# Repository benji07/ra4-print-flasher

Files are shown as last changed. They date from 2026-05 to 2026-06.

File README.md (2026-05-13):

# Print Flasher — Pre-flasher RA-4

Outil de pre-flashing pour papier photo couleur RA-4, basé sur un Arduino Uno R4 Minima et une matrice LED WS2812 8×8. Le pre-flashing consiste à exposer brièvement le papier à une lumière de faible intensité avant l'exposition principale, pour lever les ombres et/ou introduire une dominante de correction.

## Matériel (BOM)

- 1× Arduino Uno R4 Minima
- 1× Matrice LED WS2812 8×8 (64 LEDs)
- 1× Écran OLED SSD1306 128×64 I2C (adresse `0x3C`)
- 3× Potentiomètres linéaires 10 kΩ (Y, M, durée)
- 2× Boutons poussoirs (NO)
- Câblage, fils dupont

Note : un 4ᵉ potentiomètre peut être prévu physiquement mais n'est **pas câblé** dans cette version.

## Boîtiers 3D

Modèles OpenSCAD paramétriques + STL prêts à imprimer dans [`cad/`](cad/) : une boîte LED suspendue (matrice + plexi opalin) et une boîte de commande aimantée (Arduino + pile 9V + écran + commandes). Voir [`cad/README.md`](cad/README.md) pour les instructions de génération STL, BOM impression et assemblage.

## Câblage

| Composant | Pin Arduino | Remarque |
|---|---|---|
| WS2812 — DIN | D6 | idéalement via résistance 330 Ω (voir « Recommandations électriques ») |
| WS2812 — 5V (V+ IN) | 5V | OK sur USB tant que `MASTER_BRIGHTNESS` ≤ 25 |
| WS2812 — GND (V− IN, sinon V− OUT) | GND | masse commune — voir note ci-dessous |
| OLED — SDA | SDA | broche dédiée du R4 Minima |
| OLED — SCL | SCL | broche dédiée du R4 Minima |
| OLED — VCC | 3V3 ou 5V | selon le module |
| OLED — GND | GND | |
| Bouton START | D2 → GND | `INPUT_PULLUP` côté firmware |
| Bouton OLED | D3 → GND | `INPUT_PULLUP` côté firmware |
| Pot Y (curseur) | A0 | extrémités sur 5V et GND |
| Pot M (curseur) | A1 | idem |
| Pot Durée (curseur) | A2 | idem |

```
            +5V ──┬───────────── WS2812 V+ (IN, côté DIN)
                  │
                  ├── pot Y ── A0
                  ├── pot M ── A1
                  └── pot T ── A2

            GND ──┬───────────── WS2812 V- (IN si soudable, sinon V- OUT)
                  ├── tous les pots (autre extrémité)
                  ├── bouton START ── D2
                  └── bouton OLED  ── D3

            D6 ───────────────── WS2812 DIN (IN)
            SDA ──────────────── OLED SDA
            SCL ──────────────── OLED SCL
```

### Notes sur le montage physique

- **Layout matrice : row-by-row** (pas serpentine). L'indice `i` parcourt la matrice ligne par ligne, gauche → droite, ligne 0 en haut. Pour un motif (row, col), faire `row = i / 8`, `col = i % 8`. C'est pour ça qu'avec `LIT_STRIDE = 2` on voit des **rayures verticales** et pas un damier.
- **GND matrice** : sur cette matrice, le pad V− côté **IN** n'a souvent pas de trou traversant utilisable. Si tu ne peux pas y souder, raccorde le GND côté **OUT** (V− OUT) — électriquement c'est la même masse, mais soigne le contact : une pince crocodile lâche sur ce point est un contributeur classique aux glitches data sur les WS2812.
- **R330 / cap 1000 µF** : absents dans la version actuelle du montage. Le firmware compense par des défenses logicielles (double `show()` après `clear()`, refresh périodique en IDLE). Pour un montage durable ou si tu remontes `MASTER_BRIGHTNESS`, ajoute-les (voir « Recommandations électriques »).
- **Diffuseur** : prévoir un calque / plexi dépoli posé quelques mm au-dessus de la matrice. Le `LIT_STRIDE = 2` économise du courant mais produit un éclairement non uniforme (1 LED sur 2 allumée) — le diffuseur homogénéise.

## Installation des librairies

Dans Arduino IDE → **Tools → Manage Libraries…**, installer :

- `Adafruit NeoPixel` (≥ 1.12.x — version compatible Renesas RA4M1)
- `Adafruit SSD1306`
- `Adafruit GFX Library` (s'installe automatiquement comme dépendance)

Et le board package : **Tools → Board → Boards Manager…**, installer `Arduino UNO R4 Boards`. Sélectionner ensuite `Arduino UNO R4 Minima` comme carte cible.

## Upload

1. Brancher l'Arduino en USB.
2. Sélectionner la carte `Arduino UNO R4 Minima` et le bon port série.
3. Ouvrir `print-flasher.ino`.
4. **Upload**.

## Utilisation

1. **Réglages** (matrice éteinte, OLED affichant les valeurs courantes)
   - Pot Y : densité du filtre **jaune** (atténue le canal bleu). `Y=0` ↔ pas de filtre.
   - Pot M : densité du filtre **magenta** (atténue le canal vert). `M=0` ↔ pas de filtre.
   - Pot Durée : durée du flash, de **0.1 s à 10.0 s** par pas de 0.1 s.
2. **Bouton OLED** (D3) : éteint/rallume l'écran. À utiliser quand le papier est en place pour éviter tout voile parasite.
3. **Bouton START** (D2) :
   - En IDLE : déclenche le flash. L'OLED **n'est pas touché** par ce bouton — si tu veux l'éteindre pour éviter de voiler le papier, appuie sur le bouton OLED **avant** de déclencher.
   - Pendant le flash : ré-appuyer **interrompt** immédiatement l'exposition.
4. Après le flash, brève phase « DONE » (1 s) puis retour automatique en IDLE.

### Mapping couleur (rappel)

Le firmware simule une filtration soustractive d'agrandisseur :

| Sortie LED | Formule | Effet |
|---|---|---|
| Rouge | `255` (constant) | pas de filtre cyan disponible |
| Vert  | `255 − M` | M filtre le vert |
| Bleu  | `255 − Y` | Y filtre le bleu |

- `Y=0,   M=0`   → blanc (les 3 canaux à fond, ramené à 10 % par `MASTER_BRIGHTNESS`).
- `Y=255, M=255` → rouge pur.
- `Y=0,   M=255` → magenta.
- `Y=255, M=0`   → jaune.

## Sécurité / Recommandations électriques

Le firmware fixe `MASTER_BRIGHTNESS = 25` (≈ 10 % de la luminosité max). À ce niveau :

- Pic de courant matrice ≈ **380 mA** (vs. ~3.8 A à 100 %), ce qui rentre dans les **500 mA fournis par USB** sur l'Uno R4 Minima.
- Tu peux fonctionner **sans** résistance série sur la data ni condensateur de découplage, mais c'est du proto — pas du définitif.

Si tu veux remonter `MASTER_BRIGHTNESS` au-delà de ~40, ou si la matrice fait des couleurs erratiques :

- **Résistance 330 Ω** en série entre D6 et l'entrée DIN de la première LED.
- **Condensateur 1000 µF** entre +5V et GND au plus près de la matrice.
- **Alim 5V externe ≥ 4 A**, masse commune avec l'Arduino (ne **pas** alimenter la matrice par la broche 5V de l'Arduino dans ce cas).

L'OLED émet aussi de la lumière : le bouton D3 le coupe à la demande. Le firmware **ne touche jamais** à l'état physique de l'OLED de lui-même (notamment pas pendant un flash) — c'est à toi de l'éteindre via D3 avant l'exposition si tu veux éviter tout voile parasite. Pendant le flash, le rafraîchissement du contenu est suspendu mais l'écran reste dans l'état que tu as choisi.

## Workflow conseillé

1. Avec une chute de RA-4 et ton workflow d'expo habituel, faire une **bande test pre-flash** : par exemple `Y=20, M=10, Durée=0.5 s`, puis varier la durée par paliers (0.3 / 0.5 / 0.7 / 1.0 s).
2. Une fois la **durée** calée (intensité globale du pre-flash), affiner la **balance Y/M** pour ajuster la dominante.
3. Garder une fiche des valeurs qui marchent par type de papier / type de négatif (le firmware ne mémorise pas les presets pour l'instant).

## Constantes ajustables (dans le `.ino`)

| Constante | Défaut | Effet |
|---|---|---|
| `MASTER_BRIGHTNESS` | `25` | Luminosité globale 0–255. **Ne pas dépasser 40 sur USB seul.** |
| `MIN_DURATION_MS` / `MAX_DURATION_MS` | `100` / `10000` | Plage du pot durée |
| `DURATION_STEP_MS` | `100` | Pas de quantification de la durée |
| `DEBOUNCE_MS` | `15` | Anti-rebond software des boutons |
| `OLED_REFRESH_MS` | `50` | Cadence max de rafraîchissement OLED (20 Hz, redessine seulement si valeurs changent) |
| `ANALOG_SAMPLES` | `8` | Taille de la moyenne glissante sur les pots |
| `ANALOG_SAMPLE_INTERVAL_MS` | `5` | Intervalle entre 2 échantillonnages des pots (8 × 5 ms = fenêtre de filtrage de 40 ms) |

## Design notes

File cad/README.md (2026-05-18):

# Boîtiers 3D — Print Flasher

Deux boîtes imprimables, reliées par un câble 3 fils :

- **`led_box`** (95×80×30 mm) : abrite la matrice WS2812 8×8 + plexi opalin diffuseur. Se suspend sous la tête de l'agrandisseur par un trou Ø8mm.
- **`control_box`** (150×90×35 mm) : abrite l'Arduino Uno R4 Minima + pile 9V, avec sur le panneau frontal l'OLED, 3 potentiomètres (Y/M/T) et 2 boutons (GO/OLED). Aimantée à la tête de l'agrandisseur ou posée à côté.

## Architecture de fermeture

Les deux boîtes ont la même structure :
- **Corps** = fond + paroi mince (2.4 mm) + **rebord épaissi en haut** (6.5 mm × 4 mm) qui loge les aimants Ø5×2.78mm
- **Couvercle** = simple plaque plate 4 mm, avec logements aimants en miroir
- **Alignement** par 2 ergots Ø2.5×2 mm aux coins diagonalement opposés du rebord
- Les aimants se collent à la cyano dans leurs logements ; le couvercle se "clique" sur le corps

Pour la boîte commande, 4 aimants supplémentaires sont logés dans des **bossages internes au fond** et débouchent sur la face extérieure du dos — c'est ce qui aimante la boîte à la tête métallique de l'agrandisseur.

## Génération des STL

Pré-requis : OpenSCAD installé (`brew install openscad` sur macOS).

Depuis ce dossier :

```bash
openscad -o stl/led_box_body.stl     -D 'PART="body"' led_box.scad
openscad -o stl/led_box_lid.stl      -D 'PART="lid"'  led_box.scad
openscad -o stl/control_box_body.stl -D 'PART="body"' control_box.scad
openscad -o stl/control_box_lid.stl  -D 'PART="lid"'  control_box.scad
```

Pour visualiser en preview avant export : ouvrir un `.scad` dans l'app OpenSCAD, F5 pour preview, F6 pour render.

## Paramètres ajustables

Toutes les dimensions partagées sont dans `common.scad` (tolérances, dimensions composants, épaisseurs paroi). Ajuster en haut du fichier si tes composants diffèrent — par exemple :

- `MATRIX_PCB` / `MATRIX_MTG` : si ton PCB matrice fait autre chose que 65mm avec entraxe 58mm
- `MAG_D` / `MAG_H` : pour des aimants d'autre dimensions (par défaut Ø5×2.78)
- `MAG_TOL_D` / `MAG_TOL_H` : si les aimants flottent ou ne rentrent pas dans les logements
- `RIM_W` / `RIM_H` : largeur et hauteur du rebord (par défaut 6.5×4 mm — augmenter si aimants plus gros)
- `POT_HOLE` / `BTN_HOLE` : Ø des trous panneau (par défaut 7.2 mm pour les deux types)

## BOM impression / matériel

| Élément | Quantité | Notes |
|---|---|---|
| PLA noir ou PETG noir | ~150 g | Noir = anti-fuite lumineuse |
| Aimants néodyme Ø5×2.78 mm | 24 | 8 LED fermeture (4 paires) + 12 control fermeture (6 paires) + 4 control arrière (sur fond, contre tête métallique) |
| Plexi opalin 65×65×3 mm | 1 | Diffuseur |
| Vis M2.5×6 autotaraudeuses | 4 | Fixation PCB matrice |
| Vis M3×8 autotaraudeuses | 4 | Fixation Arduino |
| Vis M2×4 autotaraudeuses | 4 | Fixation OLED |
| Câble 3 conducteurs ~22AWG | 80–120 cm | 5V / GND / Data, JST mâle aux 2 bouts |
| JST-XH 3 broches mâle (sur câble) | 2 | Un à chaque extrémité du câble |
| JST-XH 3 broches femelle | 2 | Une dans chaque boîte (soudée aux fils internes) |
| Clip pile 9V | 1 | Connecteur batterie |

## Paramètres slicer conseillés

- Couches : 0.2 mm
- Périmètres : 3 (cohérent avec WALL = 2.4mm sur buse 0.4)
- Infill : 20 % gyroid (boîte commande), 30 % (boîte LED, à cause de la suspension Ø8)
- Supports : aucun (toutes les surfaces critiques sont ≤ 45° de surplomb)
- Orientation : poser chaque pièce **fond/face en bas**, surface visible vers le haut
- Bord (brim) : 5mm si décollage observé sur la boîte commande (grande surface)

## Assemblage

1. **Coller les aimants** dans tous les logements à la cyano. Faire attention à la polarité : pour chaque paire de fermeture, le pôle de l'aimant du couvercle doit attirer celui du corps (tester avec 2 aimants à la main avant de coller). Les 4 aimants arrière de la boîte commande peuvent être collés tous dans le même sens (peu importe lequel — l'autre face est la tête métallique de l'agrandisseur).
1. **Glisser les ergots du corps dans les trous du couvercle** au moment de la fermeture — c'est ce qui empêche le couvercle de glisser latéralement.
2. **Câble inter-boîtes** :
   - Câble 3 conducteurs avec un connecteur JST-XH mâle 3 broches serti à chaque extrémité (commerce ou DIY).
3. **Boîte LED** :
   - Souder 3 fils courts sur le PCB matrice (V+, V−, DIN). V− côté **IN** si soudable, sinon **OUT** (voir [`README.md`](../README.md) racine).
   - Souder l'autre bout de ces 3 fils à une embase JST-XH 3 broches femelle.
   - Visser le PCB matrice sur ses 4 plots (M2.5).
   - Glisser le plexi opalin dans la feuillure du couvercle (par-dessous le couvercle).
   - Brancher le câble inter-boîtes (JST mâle) sur l'embase femelle interne et faire sortir le câble par l'encoche de la paroi droite (au-dessus du trou de fix).
   - Fermer le couvercle (aimants + ergots).
4. **Boîte commande** :
   - Visser l'Arduino sur ses 4 plots (M3).
   - Visser l'OLED sur les 4 plots du couvercle (M2). Souder VCC / GND / SDA / SCL aux pins correspondants.
   - Câbler 3 pots (5V / curseur sur A0,A1,A2 / GND) et 2 boutons (D2,D3 vers GND).
   - Câbler la pile 9V : (+) → VIN Arduino ; (−) → GND Arduino.
   - Glisser la pile 9V entre les 4 nervures de cale.
   - Souder 3 fils dupont 5V / GND / D6 de l'Arduino à une embase JST-XH 3 broches femelle.
   - Brancher le câble inter-boîtes (JST mâle) sur l'embase femelle et faire sortir le câble par l'encoche de la paroi gauche.
   - Fermer le couvercle (aimants + ergots).

Le câble se débranche des deux côtés (JST mâle/femelle aux 2 boîtes) — pratique pour ranger ou remplacer.

## Vérification avant impression

Ouvrir chaque STL dans le slicer et vérifier visuellement :

- **`led_box_body.stl`** : trou Ø8 dans un coin, passe-câble Ø6 sur la même paroi (X+), 4 plots PCB centrés à gauche, rebord épaissi visible en haut avec 4 logements aimants ronds + 2 ergots aux coins.
- **`led_box_lid.stl`** : plaque plate avec trou central 65×65 mm aligné sur le PCB, feuillure plexi visible sur la face inférieure, trou Ø8 dans le coin, 4 logements aimants en miroir + 2 trous d'ergots.
- **`control_box_body.stl`** : plots Arduino à gauche, cale 4 nervures à droite, encoche Ø6 sur paroi gauche, rebord épaissi en haut (6 logements aimants + 2 ergots), 4 bossages internes au fond avec logements aimants traversants (visibles depuis le dessous).
- **`control_box_lid.stl`** : plaque plate avec OLED + 5 trous Ø7.2 uniformes (Y, M, T, GO, OLED), marquages texte des labels décalés ~13 mm au-dessus des trous, logements aimants en miroir + 2 trous d'ergots.

Imprimer **un coin du rebord seul** (5×5×10 mm avec un logement aimant) pour calibrer `MAG_TOL_D` avant l'impression complète.

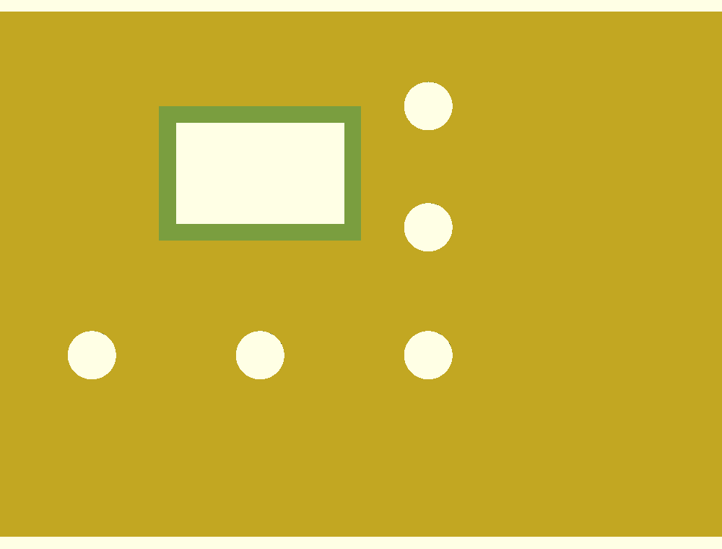
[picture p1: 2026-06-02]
cad/stl/preview_lid_control.png

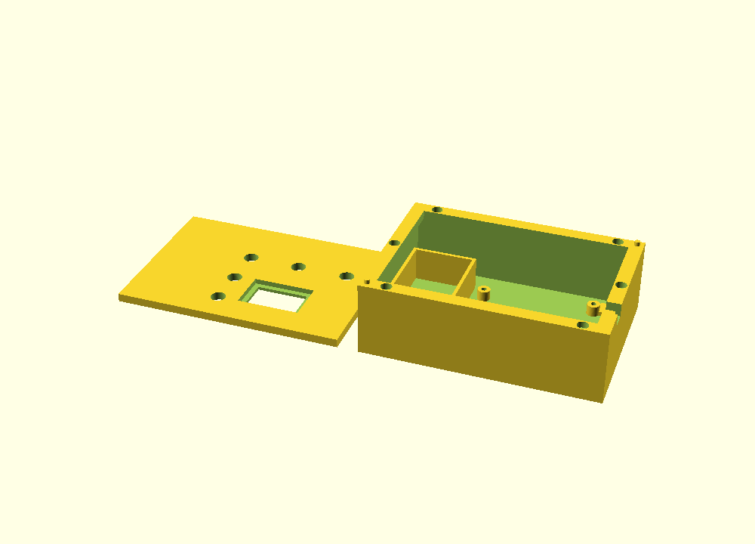
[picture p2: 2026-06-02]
cad/stl/preview_control_box.png

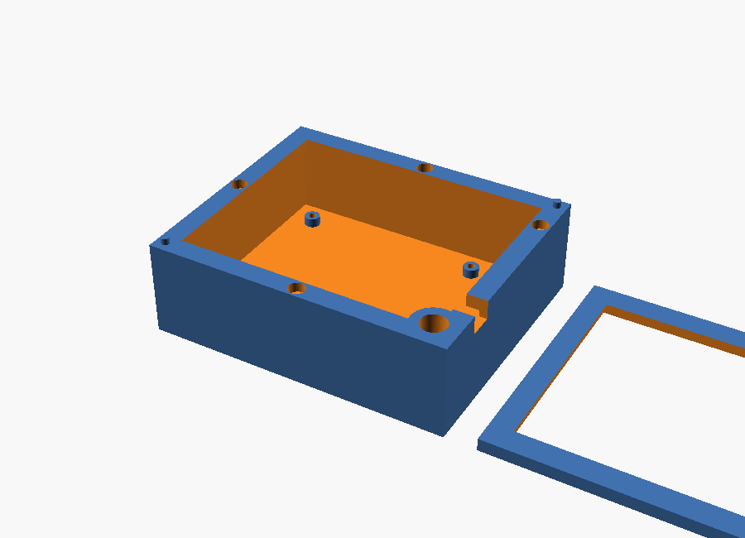
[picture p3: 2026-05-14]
cad/stl/preview_led_box.png

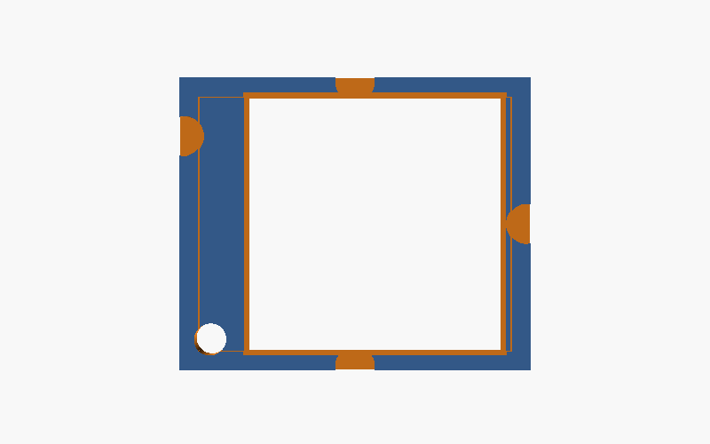
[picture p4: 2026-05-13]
cad/stl/preview_lid_led.png

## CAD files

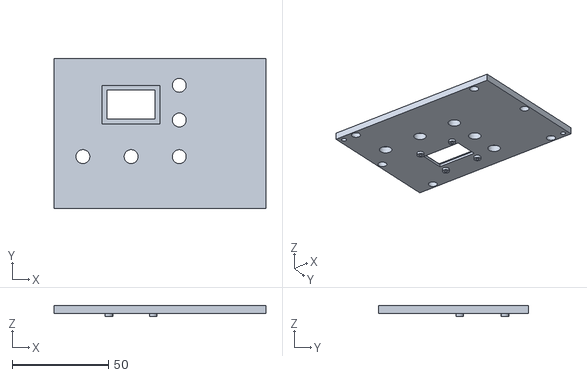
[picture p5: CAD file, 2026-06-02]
cad/stl/control_box_lid.stl
110.0 x 78.0 x 5.50

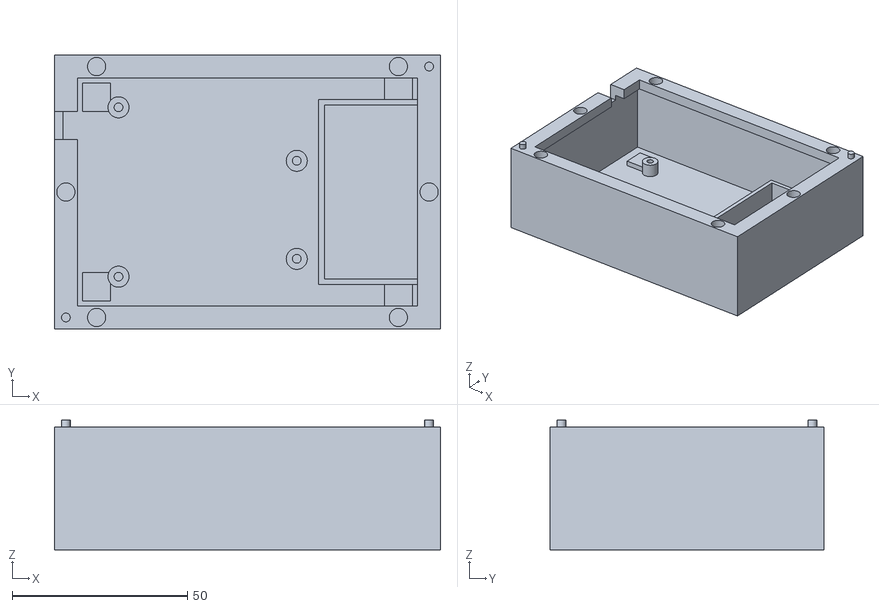
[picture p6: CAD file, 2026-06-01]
cad/stl/control_box_body.stl
110.0 x 78.0 x 37.0

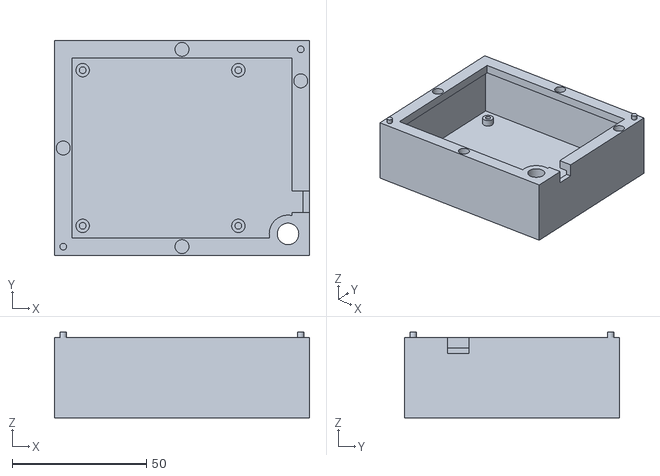
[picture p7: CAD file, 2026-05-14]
cad/stl/led_box_body.stl
95.0 x 80.0 x 32.0

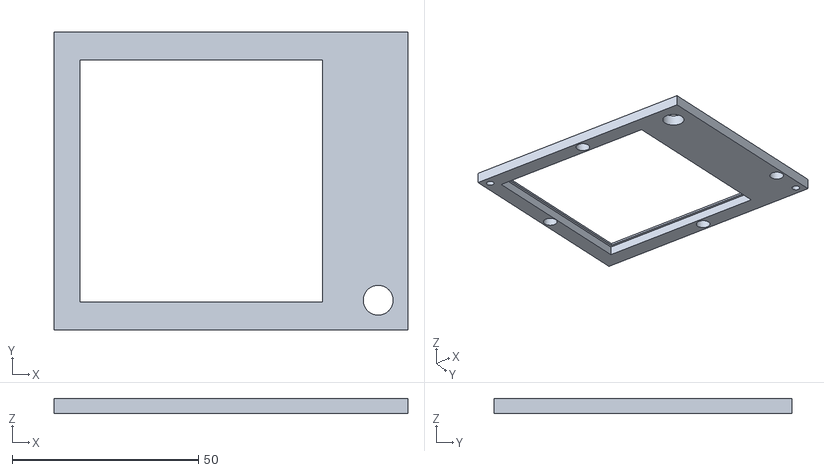
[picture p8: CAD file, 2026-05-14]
cad/stl/led_box_lid.stl
95.0 x 80.0 x 4.00

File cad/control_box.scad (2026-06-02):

// Boîte de commande — abrite l'Arduino Uno R4 Minima et la pile 9V (PP3),
// et sur le couvercle : OLED + 3 pots Y/M/T + 2 boutons GO/OLED (tous Ø7.2).
// Câble vers la boîte LED sort par la paroi gauche.
//
// Architecture : paroi mince + rebord épaissi + plaque plate.
// Aimants Ø5×2.78 : 6 en fermeture (rebord), 4 au dos (bossages internes
// au fond, débouchent sur la face extérieure pour aimanter à la tête
// d'agrandisseur). 2 ergots d'alignement.
//
// Génération STL :
//   openscad -o stl/control_box_body.stl -D 'PART="body"' control_box.scad
//   openscad -o stl/control_box_lid.stl  -D 'PART="lid"'  control_box.scad

include <common.scad>

// --- Dimensions extérieures ---
BOX_X = 110;
BOX_Y = 78;
BOX_Z = 35;

// --- Zone Arduino (PCB Uno R4 Minima, coin bas-gauche du PCB) ---
ARDUINO_X = 3;
ARDUINO_Y = (BOX_Y - ARDUINO_W) / 2;
// Trous officiels Uno (origine PCB)
ARDUINO_HOLES = [
    [15.24,  2.54],
    [15.24, 50.80],
    [66.04,  7.62],
    [66.04, 35.56]
];

// --- Zone pile 9V (à plat, calée à droite sous le rebord) ---
PP3_OUT_W  = PP3_W + PP3_TOL;    // 27.5 (petit côté, le long de X)
PP3_OUT_L  = PP3_L + PP3_TOL;    // 49.5 (long côté, le long de Y)
RIB_TH     = 1.6;
RIB_H      = 16;
PP3_X      = BOX_X - WALL - 1.6 - RIB_TH - PP3_OUT_W;   // ≈76.9
PP3_Y      = (BOX_Y - PP3_OUT_L) / 2;                   // ≈14.25, nervures symétriques

// --- Sortie câble : encoche en haut du rebord, paroi gauche X− ---
// Placée entre les aimants gauche Y=39 (milieu) et Y=74.75 (coin) pour ne pas les chevaucher.
CABLE_NOTCH_Y = 58;

// --- Couvercle : cluster regroupé (OLED + 3 pots + 2 boutons) ---
// OLED en haut, 3 pots en ligne sous l'écran (entraxe 25), 2 boutons empilés à droite.
OLED_CX = 40;  OLED_CY = 54;
POT_PITCH = 25;
POT_Y     = 27;
pot_positions = [
    [OLED_CX - POT_PITCH, POT_Y],   // [15, 27]
    [OLED_CX,             POT_Y],   // [40, 27]
    [OLED_CX + POT_PITCH, POT_Y]    // [65, 27]
];
BTN_X     = OLED_CX + POT_PITCH;    // 65 : aligné avec le pot de droite (même colonne)
btn_positions = [
    [BTN_X, 46],
    [BTN_X, 64]
];

// --- Aimants fermeture (6 sur le rebord) ---
mag_positions = [
    [12,                  MAG_PKT_OFFSET],
    [BOX_X - 12,          MAG_PKT_OFFSET],
    [12,                  BOX_Y - MAG_PKT_OFFSET],
    [BOX_X - 12,          BOX_Y - MAG_PKT_OFFSET],
    [MAG_PKT_OFFSET,      BOX_Y / 2],
    [BOX_X - MAG_PKT_OFFSET, BOX_Y / 2]
];

// --- Ergots d'alignement (2 coins diagonalement opposés) ---
peg_positions = [
    [MAG_PKT_OFFSET,         MAG_PKT_OFFSET],
    [BOX_X - MAG_PKT_OFFSET, BOX_Y - MAG_PKT_OFFSET]
];

// --- Aimants arrière (4 au dos, sur le fond, vers la tête d'agrandisseur) ---
// Les 2 du côté gauche sont sous l'Arduino, mais celui-ci est surélevé sur ses
// plots (5mm) donc aucun conflit avec le bossage (~2mm). Les 2 du côté droit sont
// décalés en Y (10 / BOX_Y-10) pour rester HORS de l'empreinte de la pile, qui
// repose directement sur le fond (sinon le bossage soulèverait la pile).
back_mag_positions = [
    [12,         12],
    [BOX_X - 12, 10],
    [12,         BOX_Y - 12],
    [BOX_X - 12, BOX_Y - 10]
];

// ─────────────────────────────────────────────────────────────────────────
module control_box_body() {
    difference() {
        union() {
            stepped_box([BOX_X, BOX_Y, BOX_Z]);
            // Plots Arduino
            for (h = ARDUINO_HOLES) {
                translate([ARDUINO_X + h.x, ARDUINO_Y + h.y, FLOOR])
                    screw_post(ARDUINO_POST_D, ARDUINO_HOLE, ARDUINO_POST_H);
            }
            // Cale pile 9V (4 nervures en U)
            translate([PP3_X - RIB_TH, PP3_Y - RIB_TH, FLOOR])
                cube([RIB_TH, PP3_OUT_L + 2*RIB_TH, RIB_H]);
            translate([PP3_X + PP3_OUT_W, PP3_Y - RIB_TH, FLOOR])
                cube([RIB_TH, PP3_OUT_L + 2*RIB_TH, RIB_H]);
            translate([PP3_X - RIB_TH, PP3_Y - RIB_TH, FLOOR])
                cube([PP3_OUT_W + 2*RIB_TH, RIB_TH, RIB_H]);
            translate([PP3_X - RIB_TH, PP3_Y + PP3_OUT_L, FLOOR])
                cube([PP3_OUT_W + 2*RIB_TH, RIB_TH, RIB_H]);
            // Bossages internes pour aimants arrière (sur la face supérieure du fond)
            for (p = back_mag_positions) floor_boss(p);
            // Ergots d'alignement
            for (p = peg_positions) rim_peg(p, BOX_Z);
        }
        // Passe-câble : encoche en haut du rebord, paroi gauche
        cable_notch("L", CABLE_NOTCH_Y, [BOX_X, BOX_Y, BOX_Z]);
        // Aimants fermeture (rebord)
        for (p = mag_positions) rim_mag_pocket(p, BOX_Z);
        // Aimants arrière (carvés depuis la face extérieure du fond, à travers le bossage)
        for (p = back_mag_positions) floor_mag_pocket(p);
    }
}

// ─────────────────────────────────────────────────────────────────────────
module control_box_lid() {
    difference() {
        union() {
            cube([BOX_X, BOX_Y, LID_TH]);
            // Plots OLED (à l'intérieur, sous le couvercle)
            translate([OLED_CX, OLED_CY, 0])
                for (sx = [-1, 1], sy = [-1, 1]) {
                    translate([sx * OLED_MTG_DX/2, sy * OLED_MTG_DY/2, -OLED_POST_H])
                        screw_post(OLED_POST_D, OLED_MTG_D, OLED_POST_H);
                }
        }
        // Fenêtre OLED (traversante)
        translate([OLED_CX - OLED_WIN_W/2, OLED_CY - OLED_WIN_H/2, -0.1])
            cube([OLED_WIN_W, OLED_WIN_H, LID_TH + 0.2]);
        // Feuillure (bezel) côté extérieur : amincit la fenêtre à ~1.5mm de membrane
        translate([OLED_CX - OLED_BEZEL_W/2, OLED_CY - OLED_BEZEL_H/2, LID_TH - OLED_BEZEL_D])
            cube([OLED_BEZEL_W, OLED_BEZEL_H, OLED_BEZEL_D + 0.1]);
        // 3 trous pots (en ligne sous l'écran) + 2 trous boutons (empilés à droite)
        for (p = pot_positions)
            translate([p.x, p.y, -0.1]) cylinder(d=POT_HOLE, h=LID_TH + 0.2);
        for (p = btn_positions)
            translate([p.x, p.y, -0.1]) cylinder(d=BTN_HOLE, h=LID_TH + 0.2);
        // Logements aimants miroirs du corps
        for (p = mag_positions) lid_mag_pocket(p);
        // Trous d'ergots
        for (p = peg_positions) lid_peg_hole(p);
    }
}

// ─────────────────────────────────────────────────────────────────────────
PART = "both";

if      (PART == "body") control_box_body();
else if (PART == "lid")  translate([0, 0, BOX_Z + 10]) control_box_lid();
else {
    control_box_body();
    translate([BOX_X + 10, 0, 0]) control_box_lid();
}

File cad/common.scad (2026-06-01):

// Variables paramétriques partagées entre led_box.scad et control_box.scad.
// Ajuster ces valeurs ici en cas de mesures différentes sur tes composants
// (PCB matrice, écrans OLED, aimants, etc.).

// --- Impression / paroi ---
WALL          = 2.4;   // épaisseur paroi standard (3 perimeters @ 0.4mm)
FLOOR         = 2.0;   // épaisseur fond
LID_TH        = 4.0;   // épaisseur couvercle (suffisante pour loger l'aimant dans le plat)
$fn           = 64;

// --- Aimants néodyme Ø5×2.78 ---
MAG_D         = 5;
MAG_H         = 2.78;
MAG_TOL_D     = 0.2;
MAG_TOL_H     = 0.2;

// --- Rebord épaissi en haut du corps (loge les aimants) ---
// Le corps a des parois minces (WALL) sur la majeure partie de sa hauteur,
// et une section plus large (RIM_W) sur les RIM_H derniers mm pour pouvoir
// percer un logement Ø(MAG_D+jeu) sans casser la paroi.
RIM_W         = 6.5;                          // largeur rebord (vue de dessus)
RIM_H         = MAG_H + MAG_TOL_H + 1.0;      // hauteur ~4mm : magnet + 1mm de matière "plafond" sous le couvercle
MAG_PKT_OFFSET = RIM_W / 2;                   // 3.25mm : centre du logement, depuis la face extérieure

// --- Ergots d'alignement couvercle/corps (2 par boîte, coins diagonalement opposés) ---
PEG_D         = 2.5;
PEG_H         = 2.0;
PEG_HOLE_D    = 2.9;                          // jeu confortable dans le couvercle
PEG_HOLE_H    = PEG_H + 0.5;

// --- Bossage interne au fond (pour les aimants arrière de la boîte commande) ---
FLOOR_BOSS_W  = MAG_D + 3;                    // 8mm carré
FLOOR_BOSS_H  = MAG_H + MAG_TOL_H + 1.0;      // mesuré depuis la face extérieure du fond

// --- Plexi opalin ---
PLEXI_TH      = 3;
PLEXI_TOL     = 0.4;

// --- Matrice WS2812 ---
MATRIX_PCB    = 65;
MATRIX_HOLE   = 65;
MATRIX_MTG    = 58;
MATRIX_MTG_D  = 2.5;
MATRIX_POST_D = 5;
MATRIX_POST_H = 3;

// --- Composants panneau ---
POT_HOLE      = 7.2;    // Ø trou pot R09
BTN_HOLE      = 7.2;    // Ø trou bouton 6×6mm avec capuchon — corrigé d'après le modèle utilisateur
OLED_WIN_W    = 25;
OLED_WIN_H    = 15;
OLED_OUTER    = 28;
OLED_MTG_DX   = 23;
OLED_MTG_DY   = 23.5;
OLED_MTG_D    = 1.8;
OLED_POST_D   = 4;
OLED_POST_H   = 1.5;   // plots courts : le verre du LCD (~1mm saillant) arrive ~0.5mm
                       // sous la face interne au lieu de ~3mm avec les anciens 4mm.
// Feuillure (bezel) côté EXTÉRIEUR : amincit le tunnel de la fenêtre de 4mm à ~1.5mm
// de membrane, pour que l'écran lise proche de la surface. Rebord large (~2.5mm) robuste.
// (Un lamage côté intérieur n'aurait PAS rapproché l'écran : c'est la hauteur des plots
//  qui fixe la profondeur de l'écran, pas le creusement de la face interne.)
OLED_BEZEL_W  = OLED_WIN_W + 5;   // 30
OLED_BEZEL_H  = OLED_WIN_H + 5;   // 20
OLED_BEZEL_D  = 2.5;              // profondeur depuis la face supérieure (laisse 1.5mm de membrane)

// --- Arduino Uno R4 Minima ---
ARDUINO_W     = 53.34;
ARDUINO_L     = 68.85;
ARDUINO_POST_D= 6;
ARDUINO_HOLE  = 2.5;
ARDUINO_POST_H= 5;

// --- Pile 9V PP3 ---
PP3_L         = 48.5;
PP3_W         = 26.5;
PP3_H         = 17.5;
PP3_TOL       = 1.0;

// --- Interrupteur rocker 15×10mm ---
ROCKER_HOLE_W = 13.2;
ROCKER_HOLE_H = 8.2;

// --- Câble inter-boîtes : encoche en haut de la paroi (au niveau du rebord) ---
// Le câble exit la boîte par une encoche rectangulaire ouverte vers le haut,
// fermée par le couvercle. Imprimable sans support, pas de jonction câble/PCB
// dans la boîte (JST des 2 côtés → câble débrochable des 2 boîtes).
NOTCH_W       = 8.0;    // largeur (Ø câble ~6mm + jeu)
NOTCH_D       = 6.0;    // profondeur depuis le haut du rebord (laisse passer Ø6 confortablement)

// Encoche traversante dans la paroi, ouverte vers Z+.
//   side ∈ "L", "R", "F", "B"
//   t    : position le long de la paroi (Y pour L/R, X pour F/B)
//   box  : [BOX_X, BOX_Y, BOX_Z]
module cable_notch(side, t, box) {
    if (side == "L") {
        translate([-0.1, t - NOTCH_W/2, box.z - NOTCH_D])
            cube([RIM_W + 0.2, NOTCH_W, NOTCH_D + 0.1]);
    } else if (side == "R") {
        translate([box.x - RIM_W - 0.1, t - NOTCH_W/2, box.z - NOTCH_D])
            cube([RIM_W + 0.2, NOTCH_W, NOTCH_D + 0.1]);
    } else if (side == "F") {
        translate([t - NOTCH_W/2, -0.1, box.z - NOTCH_D])
            cube([NOTCH_W, RIM_W + 0.2, NOTCH_D + 0.1]);
    } else if (side == "B") {
        translate([t - NOTCH_W/2, box.y - RIM_W - 0.1, box.z - NOTCH_D])
            cube([NOTCH_W, RIM_W + 0.2, NOTCH_D + 0.1]);
    }
}

// ============================================================================
// Helpers géométriques
// ============================================================================

// Corps de boîte : fond + paroi mince + rebord épaissi en haut.
//   - fond plein de Z=0 à Z=FLOOR
//   - paroi WALL épaisse de Z=FLOOR à Z=dim.z-RIM_H
//   - rebord RIM_W épais de Z=dim.z-RIM_H à Z=dim.z (loge les aimants)
module stepped_box(dim) {
    union() {
        // Fond + paroi mince
        difference() {
            cube([dim.x, dim.y, dim.z - RIM_H]);
            translate([WALL, WALL, FLOOR])
                cube([dim.x - 2*WALL, dim.y - 2*WALL, dim.z - RIM_H + 0.1]);
        }
        // Rebord épaissi
        translate([0, 0, dim.z - RIM_H])
            difference() {
                cube([dim.x, dim.y, RIM_H]);
                translate([RIM_W, RIM_W, -0.1])
                    cube([dim.x - 2*RIM_W, dim.y - 2*RIM_W, RIM_H + 0.2]);
            }
    }
}

// Logement aimant carvé dans le rebord du corps, ouvert vers le haut (Z+).
// L'aimant se glisse depuis le haut avant fermeture, fixé à la cyano.
module rim_mag_pocket(p, box_z) {
    translate([p.x, p.y, box_z - MAG_H - MAG_TOL_H])
        cylinder(d=MAG_D + MAG_TOL_D, h=MAG_H + MAG_TOL_H + 0.1);
}

// Logement aimant dans le couvercle, carvé depuis la face inférieure (Z-).
module lid_mag_pocket(p) {
    translate([p.x, p.y, -0.1])
        cylinder(d=MAG_D + MAG_TOL_D, h=MAG_H + MAG_TOL_H + 0.1);
}

// Ergot d'alignement sur le rebord du corps (cylindre debout au sommet).
module rim_peg(p, box_z) {
    translate([p.x, p.y, box_z])
        cylinder(d=PEG_D, h=PEG_H);
}

// Trou d'ergot dans le couvercle (cylindre soustractif depuis la face inférieure).
module lid_peg_hole(p) {
    translate([p.x, p.y, -0.1])
        cylinder(d=PEG_HOLE_D, h=PEG_HOLE_H);
}

// Bossage interne au fond (pour aimant arrière sur la face extérieure du fond).
// Cube en union, centré sur (p.x, p.y), assis sur la face interne du fond.
module floor_boss(p) {
    translate([p.x - FLOOR_BOSS_W/2, p.y - FLOOR_BOSS_W/2, FLOOR])
        cube([FLOOR_BOSS_W, FLOOR_BOSS_W, FLOOR_BOSS_H - FLOOR]);
}

// Logement aimant dans le fond, carvé depuis la face EXTÉRIEURE (Z=0 vers Z+).
// L'aimant se glisse depuis le dessous, fixé à la cyano.
module floor_mag_pocket(p) {
    translate([p.x, p.y, -0.1])
        cylinder(d=MAG_D + MAG_TOL_D, h=MAG_H + MAG_TOL_H + 0.1);
}

// Plot vissable cylindrique.
module screw_post(post_d, hole_d, h) {
    difference() {
        cylinder(d=post_d, h=h);
        translate([0, 0, -0.1])
            cylinder(d=hole_d, h=h + 0.2);
    }
}

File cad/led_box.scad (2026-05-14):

// Boîte LED — abrite la matrice WS2812 8×8, suspendue sous la tête d'agrandisseur.
// Le câble et le trou de suspension Ø8 sont sur la même paroi (X+).
//
// Architecture : paroi mince (WALL) + rebord épaissi en haut (RIM_W × RIM_H)
// qui loge les aimants néodyme Ø5×2.78mm.
// Couvercle = simple plaque plate avec logements aimants en miroir,
// alignement par 2 ergots aux coins diagonalement opposés.
//
// Génération STL :
//   openscad -o stl/led_box_body.stl -D 'PART="body"' led_box.scad
//   openscad -o stl/led_box_lid.stl  -D 'PART="lid"'  led_box.scad

include <common.scad>

// --- Dimensions extérieures ---
BOX_X = 95;
BOX_Y = 80;
BOX_Z = 30;

// --- Trou de fixation suspension ---
FIX_HOLE_D    = 8.0;
FIX_BOSS_D    = 14.0;
FIX_CORNER_X  = BOX_X - 8;
FIX_CORNER_Y  = 8;

// --- PCB matrice (collé au côté gauche X−, centré en Y) ---
PCB_OFFSET_X  = 7;
PCB_OFFSET_Y  = (BOX_Y - MATRIX_PCB) / 2;
PCB_CENTER_X  = PCB_OFFSET_X + MATRIX_PCB / 2;
PCB_CENTER_Y  = BOX_Y / 2;

// --- Trou couvercle aligné sur le PCB ---
HOLE_CENTER_X = PCB_CENTER_X;
HOLE_CENTER_Y = PCB_CENTER_Y;

// --- Sortie câble : encoche en haut du rebord, paroi droite X+, au-dessus du bossage de fix ---
CABLE_NOTCH_Y = FIX_CORNER_Y + FIX_BOSS_D/2 + 5;  // 20mm — au-dessus du bossage

// --- Positions aimants (4 sur le rebord, 1 par côté) ---
mag_positions = [
    [MAG_PKT_OFFSET,           BOX_Y / 2],          // gauche
    [BOX_X - MAG_PKT_OFFSET,   BOX_Y - 15],         // droite (haute, loin du câble bas)
    [BOX_X / 2,                MAG_PKT_OFFSET],     // devant
    [BOX_X / 2,                BOX_Y - MAG_PKT_OFFSET] // derrière
];

// --- Ergots d'alignement (2 coins diagonalement opposés du rebord) ---
peg_positions = [
    [MAG_PKT_OFFSET,           MAG_PKT_OFFSET],
    [BOX_X - MAG_PKT_OFFSET,   BOX_Y - MAG_PKT_OFFSET]
];

// ─────────────────────────────────────────────────────────────────────────
module led_box_body() {
    difference() {
        union() {
            stepped_box([BOX_X, BOX_Y, BOX_Z]);
            // Bossage de renfort autour du trou de fixation (intérieur)
            translate([FIX_CORNER_X, FIX_CORNER_Y, 0])
                cylinder(d=FIX_BOSS_D, h=BOX_Z);
            // Plots PCB matrice
            for (sx = [-1, 1], sy = [-1, 1]) {
                translate([
                    PCB_CENTER_X + sx * MATRIX_MTG/2,
                    PCB_CENTER_Y + sy * MATRIX_MTG/2,
                    FLOOR
                ])
                    screw_post(MATRIX_POST_D, MATRIX_MTG_D, MATRIX_POST_H);
            }
            // Ergots d'alignement
            for (p = peg_positions) rim_peg(p, BOX_Z);
        }
        // Trou de fixation Ø8 traversant
        translate([FIX_CORNER_X, FIX_CORNER_Y, -0.1])
            cylinder(d=FIX_HOLE_D, h=BOX_Z + 0.2);
        // Passe-câble : encoche en haut du rebord, paroi droite
        cable_notch("R", CABLE_NOTCH_Y, [BOX_X, BOX_Y, BOX_Z]);
        // Logements aimants dans le rebord
        for (p = mag_positions) rim_mag_pocket(p, BOX_Z);
    }
}

// ─────────────────────────────────────────────────────────────────────────
module led_box_lid() {
    difference() {
        cube([BOX_X, BOX_Y, LID_TH]);
        // Trou central matrice (traversant)
        translate([
            HOLE_CENTER_X - MATRIX_HOLE/2,
            HOLE_CENTER_Y - MATRIX_HOLE/2,
            -0.1
        ])
            cube([MATRIX_HOLE, MATRIX_HOLE, LID_TH + 0.2]);
        // Feuillure plexi sur la face inférieure
        translate([
            HOLE_CENTER_X - (MATRIX_HOLE + 2)/2,
            HOLE_CENTER_Y - (MATRIX_HOLE + 2)/2,
            -0.1
        ])
            cube([MATRIX_HOLE + 2, MATRIX_HOLE + 2, PLEXI_TH + PLEXI_TOL]);
        // Trou Ø8 fixation aligné sur le corps
        translate([FIX_CORNER_X, FIX_CORNER_Y, -0.1])
            cylinder(d=FIX_HOLE_D, h=LID_TH + 0.2);
        // Logements aimants miroirs du corps
        for (p = mag_positions) lid_mag_pocket(p);
        // Trous d'ergots
        for (p = peg_positions) lid_peg_hole(p);
    }
}

// ─────────────────────────────────────────────────────────────────────────
PART = "both";

if      (PART == "body") led_box_body();
else if (PART == "lid")  translate([0, 0, BOX_Z + 10]) led_box_lid();
else {
    led_box_body();
    translate([BOX_X + 10, 0, 0]) led_box_lid();
}

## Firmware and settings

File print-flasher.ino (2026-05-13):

// Pre-flasher RA-4 — Arduino Uno R4 Minima
// Matrice WS2812 8x8 + OLED SSD1306 128x64 I2C + 3 pots + 2 boutons

#include <Adafruit_NeoPixel.h>
#include <Adafruit_GFX.h>
#include <Adafruit_SSD1306.h>

// --- Pins ---
#define LED_PIN        6
#define BTN_START      2
#define BTN_OLED       3
#define POT_Y         A0
#define POT_M         A1
#define POT_DURATION  A2

// --- Constantes ---
#define NUM_LEDS                    64
#define LIT_STRIDE                   2     // n'allume qu'une LED sur N (1=toutes, 2=moitie, 4=quart)
#define MASTER_BRIGHTNESS           10     // 0-255, ~4 % (plus bas = plus de plage utile sur le pot duree)
#define MIN_DURATION_MS            100
#define MAX_DURATION_MS          10000
#define DURATION_STEP_MS           100
#define DURATION_STEPS             ((MAX_DURATION_MS - MIN_DURATION_MS) / DURATION_STEP_MS + 1)
#define DEBOUNCE_MS                 15
#define OLED_REFRESH_MS             50
#define ANALOG_SAMPLES               8
#define ANALOG_SAMPLE_INTERVAL_MS    5
#define DONE_DURATION_MS          1000

// --- OLED ---
#define SCREEN_WIDTH  128
#define SCREEN_HEIGHT  64
#define OLED_RESET     -1
#define OLED_ADDRESS 0x3C

Adafruit_NeoPixel strip(NUM_LEDS, LED_PIN, NEO_GRB + NEO_KHZ800);
Adafruit_SSD1306 display(SCREEN_WIDTH, SCREEN_HEIGHT, &Wire, OLED_RESET);

// --- Etat ---
enum State { IDLE, EXPOSING, DONE };
State currentState = IDLE;

unsigned long exposureStartMs    = 0;
unsigned long exposureDurationMs = MIN_DURATION_MS;
uint8_t       exposureY          = 0;
uint8_t       exposureM          = 0;
unsigned long doneStartMs        = 0;
unsigned long lastOledRefreshMs  = 0;

bool oledUserOn = true;

// Filtrage analogique (moyenne glissante)
uint16_t analogBuf[3][ANALOG_SAMPLES];
uint8_t  analogIdx    = 0;
bool     analogFilled = false;

// --- Boutons ---
struct Button {
  uint8_t pin;
  bool lastReading;
  bool stableState;
  unsigned long lastChangeMs;
};
Button btnStart = { BTN_START, HIGH, HIGH, 0 };
Button btnOled  = { BTN_OLED,  HIGH, HIGH, 0 };

bool handleButton(Button &b) {
  bool reading = digitalRead(b.pin);
  unsigned long now = millis();
  bool pressed = false;
  if (reading != b.lastReading) {
    b.lastReading  = reading;
    b.lastChangeMs = now;
  }
  if ((now - b.lastChangeMs) >= DEBOUNCE_MS && reading != b.stableState) {
    b.stableState = reading;
    if (b.stableState == LOW) pressed = true;  // INPUT_PULLUP : LOW = appuye
  }
  return pressed;
}

// --- Lecture pots filtree ---
void sampleAnalog() {
  analogBuf[0][analogIdx] = analogRead(POT_Y);
  analogBuf[1][analogIdx] = analogRead(POT_M);
  analogBuf[2][analogIdx] = analogRead(POT_DURATION);
  analogIdx = (analogIdx + 1) % ANALOG_SAMPLES;
  if (analogIdx == 0) analogFilled = true;
}

uint16_t getFiltered(uint8_t channel) {
  uint8_t count = analogFilled ? ANALOG_SAMPLES : analogIdx;
  if (count == 0) count = 1;
  uint32_t sum = 0;
  for (uint8_t i = 0; i < count; i++) sum += analogBuf[channel][i];
  return sum / count;
}

uint8_t getYDensity()        { return map(getFiltered(0), 0, 1023, 0, 255); }
uint8_t getMDensity()        { return map(getFiltered(1), 0, 1023, 0, 255); }
unsigned long getDurationMs() {
  uint16_t steps = map(getFiltered(2), 0, 1023, 0, DURATION_STEPS - 1);
  return MIN_DURATION_MS + (unsigned long)steps * DURATION_STEP_MS;
}

// --- Matrice ---
void applyColor(uint8_t y, uint8_t m) {
  uint32_t c = strip.Color(255, 255 - m, 255 - y);
  strip.clear();
  for (uint16_t i = 0; i < NUM_LEDS; i += LIT_STRIDE) {
    strip.setPixelColor(i, c);
  }
  strip.show();
}

void clearStrip() {
  strip.clear();
  strip.show();
  delayMicroseconds(300);  // > 50 us de latch WS2812
  strip.show();            // 2e trame : rattrape un bit corrompu dans la 1ere
}

// --- OLED ---
void oledOn()  { display.ssd1306_command(SSD1306_DISPLAYON);  }
void oledOff() { display.ssd1306_command(SSD1306_DISPLAYOFF); }

void oledShow(uint8_t y, uint8_t m, unsigned long durMs, const char* status) {
  display.clearDisplay();
  display.setTextColor(SSD1306_WHITE);

  // Zone jaune (y = 0 - 15) : titre + statut
  display.setTextSize(1);
  display.setCursor(0, 0);
  display.print("PRE-FLASH RA-4");
  display.setCursor(0, 8);
  display.print("[ ");
  display.print(status);
  display.print(" ]");

  // Zone bleue (y = 16 - 63) : valeurs Y / M / T
  char buf[24];
  display.setTextSize(2);
  display.setCursor(0, 18);
  snprintf(buf, sizeof(buf), "Y%03u M%03u", y, m);
  display.print(buf);

  unsigned long whole  = durMs / 1000;
  unsigned long tenths = (durMs / 100) % 10;
  display.setCursor(0, 40);
  snprintf(buf, sizeof(buf), "T %02lu.%lus", whole, tenths);
  display.print(buf);

  display.display();
}

// --- Setup ---
void setup() {
  pinMode(BTN_START, INPUT_PULLUP);
  pinMode(BTN_OLED,  INPUT_PULLUP);

  // Matrice : tout a zero AVANT le premier show, paper-safe au boot
  strip.begin();
  strip.setBrightness(MASTER_BRIGHTNESS);
  strip.clear();
  strip.show();
  delayMicroseconds(300);
  strip.show();  // 2e trame pour garantir all-off au demarrage

  // OLED : laisse le charge pump SSD1306 stabiliser, puis retry borne
  delay(100);
  unsigned long oledStartMs = millis();
  while (!display.begin(SSD1306_SWITCHCAPVCC, OLED_ADDRESS)) {
    if (millis() - oledStartMs >= 2000) break;  // abandon apres 2 s si OLED HS
    delay(100);
  }
  display.clearDisplay();
  display.display();
}

// --- Loop ---
void loop() {
  unsigned long now = millis();

  static unsigned long lastAnalogSampleMs = 0;
  if ((now - lastAnalogSampleMs) >= ANALOG_SAMPLE_INTERVAL_MS) {
    lastAnalogSampleMs = now;
    sampleAnalog();
  }

  uint8_t y = getYDensity();
  uint8_t m = getMDensity();
  unsigned long dur = getDurationMs();

  bool startPressed = handleButton(btnStart);
  bool oledPressed  = handleButton(btnOled);

  if (oledPressed) {
    oledUserOn = !oledUserOn;
    if (oledUserOn) oledOn(); else oledOff();
  }

  switch (currentState) {
    case IDLE: {
      static unsigned long lastIdleRefreshMs = 0;
      if ((now - lastIdleRefreshMs) >= 100) {
        lastIdleRefreshMs = now;
        strip.show();  // buffer deja a zero, on re-flush au cas ou une LED a glitche
      }
      if (startPressed) {
        exposureDurationMs = dur;
        exposureStartMs    = now;
        exposureY          = y;
        exposureM          = m;
        applyColor(y, m);
        currentState = EXPOSING;
      }
      break;
    }

    case EXPOSING:
      if (startPressed || (now - exposureStartMs) >= exposureDurationMs) {
        clearStrip();
        doneStartMs = now;
        currentState = DONE;
      }
      break;

    case DONE:
      if ((now - doneStartMs) >= DONE_DURATION_MS) {
        currentState = IDLE;
      }
      break;
  }

  if (oledUserOn && (now - lastOledRefreshMs) >= OLED_REFRESH_MS) {
    lastOledRefreshMs = now;

    uint8_t showY = y;
    uint8_t showM = m;
    unsigned long showDur = dur;
    const char* status = "READY";

    if (currentState == EXPOSING) {
      unsigned long elapsed   = now - exposureStartMs;
      unsigned long remaining = (elapsed >= exposureDurationMs) ? 0 : (exposureDurationMs - elapsed);
      // Arrondi au dixieme superieur : on lit 0.1 juste avant la fin, jamais 0.0
      showDur = ((remaining + DURATION_STEP_MS - 1) / DURATION_STEP_MS) * DURATION_STEP_MS;
      showY   = exposureY;
      showM   = exposureM;
      status  = "EXPOSING";
    } else if (currentState == DONE) {
      status = "DONE";
    }

    static bool prevValid = false;
    static uint8_t prevY, prevM;
    static unsigned long prevDur;
    static State prevState;
    if (!prevValid || showY != prevY || showM != prevM || showDur != prevDur || currentState != prevState) {
      oledShow(showY, showM, showDur, status);
      prevY = showY; prevM = showM; prevDur = showDur; prevState = currentState;
      prevValid = true;
    }
  }
}

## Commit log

2026-05-12 OLED bi-color layout and live countdown
    - Adapt screen layout to bi-color OLED (yellow row at top, blue below):
    title + status in the yellow band, Y/M/T values in the blue band
    - START button no longer touches the OLED -- only the dedicated OLED
    button (D3) controls its on/off state
    - Show live countdown during EXPOSING when the OLED is on, with Y/M
    frozen at the values captured on START
    - Allow OLED toggle during EXPOSING now that START no longer forces it off
    [print-flasher.ino]
2026-05-13 Add 3D enclosure designs (OpenSCAD + STL)
    Two-box layout connected by a 3-wire cable:
    - LED box (90x75x30): WS2812 matrix + opal plexi diffuser,
    Ø8mm suspension hole and cable exit on the same wall so the
    cable follows the suspension axis.
    - Control box (150x90x35): Arduino Uno R4 Minima + 9V battery +
    side rocker switch; front panel hosts OLED, 3 pots, 2 buttons.
    Closure via Ø10x3 neodymium magnets recessed into the rims (no
    screws). Parametric — all tolerances/component dims live in
    common.scad.
    [common.scad, control_box.scad, control_box_body.stl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]
2026-05-14 Rework magnet housing + fix button hole size
    - Magnets: Ø10×3 → Ø5×2.78. Previous Ø10 pockets were wider than
    the 2.4mm walls and would have broken through.
    - New architecture: thin walls + thickened rim (6.5mm × 4mm) at the
    top of each box body, which properly houses the magnet pockets.
    Lids become simple 4mm flat plates with mirror pockets; alignment
    via 2 small pegs at diagonally opposite corners.
    - Control-box back-mount magnets sit in internal floor bosses, opening
    outward on the underside (attract to enlarger head).
    - BTN_HOLE 12.2 → 7.2 (buttons are Ø7, not Ø12 as initially assumed).
    Panel now has 5 uniform Ø7.2 holes.
    - LED box 90×75 → 95×80 to accommodat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
    [common.scad, control_box.scad, control_box_body.stl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]
2026-05-14 Cable passthrough as top-rim notch + JST both sides
    - Replace horizontal Ø6 cable hole with a top-rim notch (open upward,
    closed by the lid). Notch sits at the rim/lid junction and prints
    natively without supports.
    - Drop internal cable-clamp pegs — strain relief is now provided by
    the JST connector inside the box (too wide to slip back through
    the notch).
    - Cable is JST-XH male on both ends; each box has a JST-XH female
    header soldered to its internal wires. Cable becomes fully
    detachable from both boxes.
    - Remove .DS_Store from tracking; add .gitignore.
    [common.scad, control_box.scad, control_box_body.stl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]
2026-05-18 Control box: drop rocker hole + push panel labels further from holes
    - Body: remove the 13.2×8.2 mm rocker switch cutout from the right wall.
    Power wiring goes directly battery → VIN / GND.
    - Lid: move Y/M/T/GO/OLED engraved labels from PANEL_Y+8 to PANEL_Y+13
    so they clear pot/button caps (margin 2.65 → 7.65 mm).
    - Regenerate the two affected STLs; LED box STLs untouched.
    - README BOM + assembly + visual-check updated to match.
    [control_box.scad, control_box_body.stl, control_box_lid.stl]
2026-06-01 Boîte de commande : layout regroupé, boîte plus compacte, écran rapproché
    Suite aux retours après impression du couvercle :
    - Supprime toutes les gravures (labels Y/M/T/GO/OLED + logo PRINT FLASHER).
    - Pots : entraxe 25 mm (au lieu de 15) pour que les corps/capuchons ne se touchent
    plus. Nouveau layout : 3 pots en ligne sous l'écran, 2 boutons empilés à droite.
    - Fenêtre OLED 25×15 (+1 mm en largeur et hauteur).
    - Écran rapproché de la surface : plots OLED 4 → 1.5 mm + feuillure (bezel) côté
    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
    [common.scad, control_box.scad, control_box_body.stl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]
2026-06-02 Aligne les 2 boutons avec le pot de droite (même colonne X=65)
    Les boutons étaient à X=68, désormais alignés sur le pot de droite (OLED_CX +
    POT_PITCH) pour une colonne propre. STL et previews du couvercle régénérés.
    [control_box.scad, control_box_lid.stl]
